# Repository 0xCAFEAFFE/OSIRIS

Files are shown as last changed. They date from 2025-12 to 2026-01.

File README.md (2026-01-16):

## Project OSIRIS

The **O**pen **S**ource **I**onizing **R**adiation **I**ndication **S**ystem can serve as a standalone Geiger counter or dosimeter and as a data logger or true random number generator when connected to a PC. It uses widely available components and is optimized for low power consumption, making it well suited for portable operation.

:construction: The documentation is still under construction. :construction:

### Hardware Overview

The system is powered by a single cell LiPo battery through a soft-latch and MCP1640 boost converter. A high voltage supply provides 400V to the infamous SBM-20 G-M tube for radiation detection, a pulse amplifier shapes the signal for processing by the ATmega328PB microcontroller at the core of the system. A 32kHz clock crystal provides an accurate time base to the MCU. The battery can be charged through the Micro-USB connector and MCP73831 linear charger, the CH340 USB-UART bridge enumerates the device as a virtual serial COM port when connected to a PC, which can be used for updating the firmware, configuration, debugging and logging. A low power, reflective LCD, a foil keypad and an electromechanical beeper form a lean user interface, a 3D-printed snap-fit enclosure keeps everything together in a portable and compact form factor.

The circuit schematics and layout overview is released under *CC BY-NC-SA 4.0* in the `hardware/electronics` folder of this repository.

To deter copycats from profiting off this project without contributing, the manufacturing files are currently not freely available but the bare PCB is available for a symbolic fee in my [Tindie store](https://www.tindie.com/stores/0xcafeaffe/), a partially populated kit is available there as well.

The STL files for the enclosure are released under *CC BY-NC-SA 4.0* and are available in the `hardware/mechanical` folder of this repository and on [Thingiverse](https://www.thingiverse.com/thing:7263135).

### Firmware Overview

The firmware is written in C and implements a interrupt-driven, modular approach using a super-loop. The MCU spends most time in sleep mode to save power but will be woken up by various interrupts, most importantly the G-M radiation events and the 1s tick interrupt provided by the clock XTAL, which triggers the calculation of filtered radiation measurement values. A simple command parser allows the user to control the device through a serial terminal, independently of the UI. To compensate the relatively poor accuracy of the internal RC oscillator, the UART baud rate setting can be calibrated against the external clock XTAL and stored to EEPROM, a modified version of the OptiBoot bootloader loads that calibrated UART setting, which allows for faster firmware upload, which is especially useful during development.

The firmware is released under *GPL v2.0* and available in the `firmware` folder of this repository. It includes a heavily modified version of a [LCD driver library](https://www.lcd-module.de/lcd-tft-beispiel-code-programmierung/application-note/arduino.html), released under *GPL v2.0* as well as a modified version of [OptiBoot](https://github.com/Optiboot/optiboot), released under *GPL v2.0* as well.

### User Interface

Each key has primary functions assigned for short and long key presses:

| Press | Red | Yellow | Green | 
|---|---|---|---|
| Short | Power on / Mute alarm | Toggle clicker  | Cycle view mode |
| Long  | Power off | Toggle key lock | Cycle mode setting |

The following view modes can be cycled through by shortly pressing the green key, in some of which the green key has an alternative function if pressed long:

| View Mode | Green Long Function |  
|---|---|
| Dose Rate | Cycle Filter Setting  |
| Total Dose  | Reset Total Dose |
| Time | Reset System Time |
| Alarm Level | Cycle Alarm Level |
| Voltages | - |

The LCD symbols (no always visible) in the top right corner, from left to right:

 - Keylock enabled
 - Clicker enabled
 - USB connected
 - Battery state
 
The UART calibration routine can be started by holding the yellow key while powering on the device.

### Command Parser

The command parser reads ASCII input from the serial port and expects commands to be terminated with a `LF` character (`'\n', 0x0A`).
Each command consists of a single letter and an optional argument, e.g.: `a` reads out the current alarm level, `a0.5` sets the level to 0.5µSv/h, sending `?` lists all available commands.

The default Windows driver settings for the CH340 cause it to reset the MCU whenever it is connected to the PC or when the COM port is opened. To avoid that, change the following settings:

    Device Manager -> USB-SERIAL CH340 -> Properties -> Port Settings -> Advanced 

```
- [ ] Enabling The Serial Port Enumerator
- [x] Disable Modem Handshake
```

### Build Tools

The application was developed using [Microchip Studio](https://www.microchip.com/en-us/tools-resources/develop/microchip-studio), `v7.0.2594` which ships with the quite old version of `avr-gcc v5.4.0` and `DFP v2.3.518`, the project file for Microchip Studio can be found in the `mcp studio` folder.

If you prefer to build manually and/or with a more recent compiler version, then I suggest downloading this [release by ZakKemble](https://github.com/ZakKemble/avr-gcc-build/releases/tag/v15.1.0-1), which uses the same versions of `avr-gcc v15.1.0`, `binutils v2.44` and `avr-libc v2.2.1` as the latest toolchain [release by Microchip](https://www.microchip.com/en-us/tools-resources/develop/microchip-studio/gcc-compilers), but also includes matching version of `make` and `avrdude` for Windows. The Makefile was only tested on Windows but *should* work for Linux as well. Yes, I'm a Windows person, shame on me, I know, I know..

The bootloader was compiled using `avr-gcc v15.1.0` as well, resulting in a 510 byte binary which *barely* fits the boot section size of 512 bytes. The binary was smaller with the older `avr-gcc v5.4.0`, future compiler versions *might* produce a binary too large to fit.

Fuse settings: Low =0xE2, High =0xD6, Extended =0xFF.

While flashing the bootloader via ISP, USB must be connected to provide power to the system.

In case the default UART setting is way off, the bootloader might not receive the firmware correctly. I'd therefore recommend, when flashing the bootloader via ISP for the first time, to once flash the application via ISP as well, to already have the UART calibration routine in place. Once the application runs, it will auto-calibrate the UART and from there on the bootloader should work as well.

### Warnings :warning:

 - The linear charger is set to a current of 300mA, the connected battery therefore needs to have a capacity of at least 300mAh for a safe charging rate of 1C. 
 - Don't let the battery charge unattended.
 - Don't touch the high voltage path of the PCB while power is on
 - The capacitors stay charged for some for a while after turning off the device.

### Limits

I would expect the device to work up to ~1mSv/h but I don't have a test source strong enough to verify that.

The so called TRNG is only a very primitive draft and the quality of the random numbers was not verified at all.

### Disclaimer 

This device should not be considered a scientific instrument or safety equipment but an experimental development kit for the qualified, radiation-curious professional.

### Contact

Questions and feedback are appreciated!

105112757+0xCAFEAFFE@users.noreply.github.com

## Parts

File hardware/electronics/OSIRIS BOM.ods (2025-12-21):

Reference Designators | Quantity | Technology | Description | Package | Value
C11, C16, C17, C18, C20, C23, C24, C25, C26, C27, C29, C7 | 12 | SMD | Capacitor | 0603 | 100n
J1, J2 | 2 | THT | Tube Holder | FUSE-HOLDER-6.3MM | SBM20
R24 | 1 | SMD | Resistor | 0603 | n.p.
IC7 | 1 | SMD | Microcontroller | TQFP-32 | ATMEGA328PB-AI
C10 | 1 | SMD | Capacitor | 0603 | 2.2n
R33 | 1 | SMD | Resistor | 0603 | 47R
J4 | 1 | THT | Pin Header | 1X05 | ISP
IC1 | 1 | SMD | General purpose CMOS timer IC | SO-8 | ICM7555
T5 | 1 | SMD | N-Channel Mosfet | SOT23-3 | IRLML2502
L1 | 1 | THT | Vertical Ferrite Inductor | L-07HCP | 10m
T3, T4, T6 | 3 | SMD | P-Channel Mosfet | SOT23-3 | IRLML6401
R7 | 1 | SMD | Resistor | 0805 | 1M
R19 | 1 | SMD | Resistor | 0603 | 4.7k
L2 | 1 | SMD | Power Inductor | L-242418FPS | 4.7u
R6 | 1 | SMD | Resistor | 1206 | 1.5M
R20 | 1 | SMD | Resistor | 0603 | 3.3k
C1 | 1 | SMD | Capacitor | 0603 | 1nF
F1, F2 | 2 | SMD | PTC Fuse | 0805 | FSMD035-0805-R
R10, R12, R27 | 3 | SMD | Resistor | 0603 | 10k
D2, D3, D4 | 3 | THT | High Speed Rectifier Diode | D-RADIAL | UF4005
R8, R9 | 2 | SMD | Resistor | 0603 | 220k
IC2 | 1 | SMD | Quad 2-input NOR CMOS IC | SO-14 | 4001D
R21, R22, R26, R28, R29, R30, R31 | 7 | SMD | Resistor | 0603 | 100k
IC5 | 1 | SMD | USB-UART-Bridge IC | SO-16 | CH340C
IC6 | 1 | SMD | Li-Battery Linear Charger IC | SOT23-3-5 | MCP73831
T1 | 1 | SMD | Power Mosfet | DPAK4 | IRFR310
IC3 | 1 | THT | Electromechanical Beeper | BUZZER | BUZZER
R11, R17, R2 | 3 | SMD | Resistor | 0603 | 470k
C21, C22 | 2 | SMD | Capacitor | 0603 | 10pF
C5 | 1 | SMD | Capacitor | 0603 | 4.7n
T2 | 1 | SMD | Bipolar Transistor | SOT23-3 | BC848
C28 | 1 | SMD | Capacitor | 0603 | 220n
D5, D6 | 2 | THT | 200V Zener Diode | D-RADIAL | ZY200
R13, R15, R25, R32 | 4 | SMD | Resistor | 0603 | 1M
BAT1 | 1 | THT | Single Cell Lithium Polymer Battery | JST-2-PTH | 3.7V 3Ah LiPo
J3 | 1 | THT | Micro USB 2.0 Connector | MOLEX_548190519 | MINI-USB
C13, C9 | 2 | SMD | Capacitor | 0603 | 100p
IC8 | 1 | THT | 2x16 Character Low Power LCD | EA-DOGM | EA-DOGM162
R14, R16, R23, R3 | 4 | SMD | Resistor | 0603 | 100R
Y1 | 1 | THT | 32kHz Clock Crystal | TC38 | 32.768kHz
D12 | 1 | SMD | Zener Diode | SOT23-3 | 5.6V
C12, C15, C19 | 3 | SMD | Capacitor | 0805 | 4.7u
IC4 | 1 | SMD | Boost Converter IC | SOT23-3-6 | MCP1640
R1, R18 | 2 | SMD | Resistor | 0603 | 150k
J5 | 1 | THT | Pin Header | 1X04/90 | FOIL KEYPAD
R4, R5 | 2 | SMD | Resistor | 1206 | 1.8M
C2, C3, C4 | 3 | THT | High Voltage Foil Capacitor | MKP2-63022N | 22n
D1, D10, D13, D14, D7, D8, D9 | 7 | SMD | Schottky Diode | SOD-123 | BAT42
C14, C8 | 2 | SMD | Capacitor | 0805 | 22u
C6 | 1 | SMD | Capacitor | 0603 | 47n

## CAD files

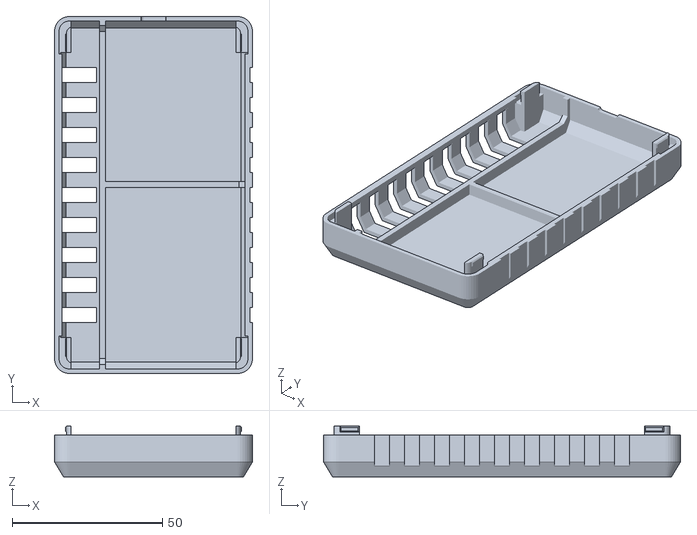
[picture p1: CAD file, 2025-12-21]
hardware/mechanical/Shell_Bottom_v3.stl
66.0 x 119.0 x 16.9

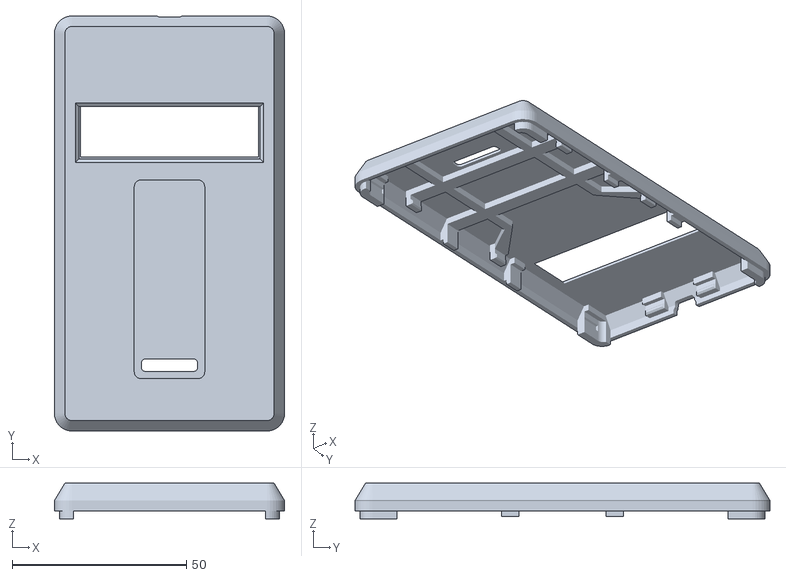
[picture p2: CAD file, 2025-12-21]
hardware/mechanical/Shell_Top_v3.stl
66.0 x 119.0 x 10.2

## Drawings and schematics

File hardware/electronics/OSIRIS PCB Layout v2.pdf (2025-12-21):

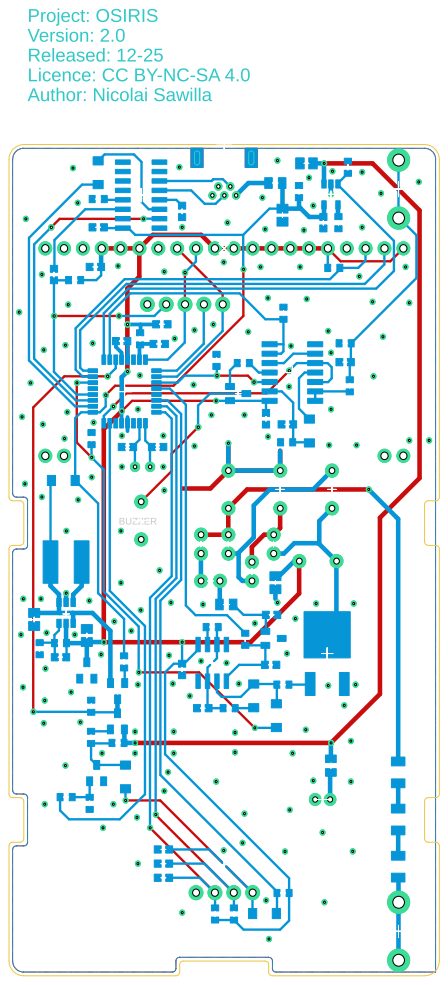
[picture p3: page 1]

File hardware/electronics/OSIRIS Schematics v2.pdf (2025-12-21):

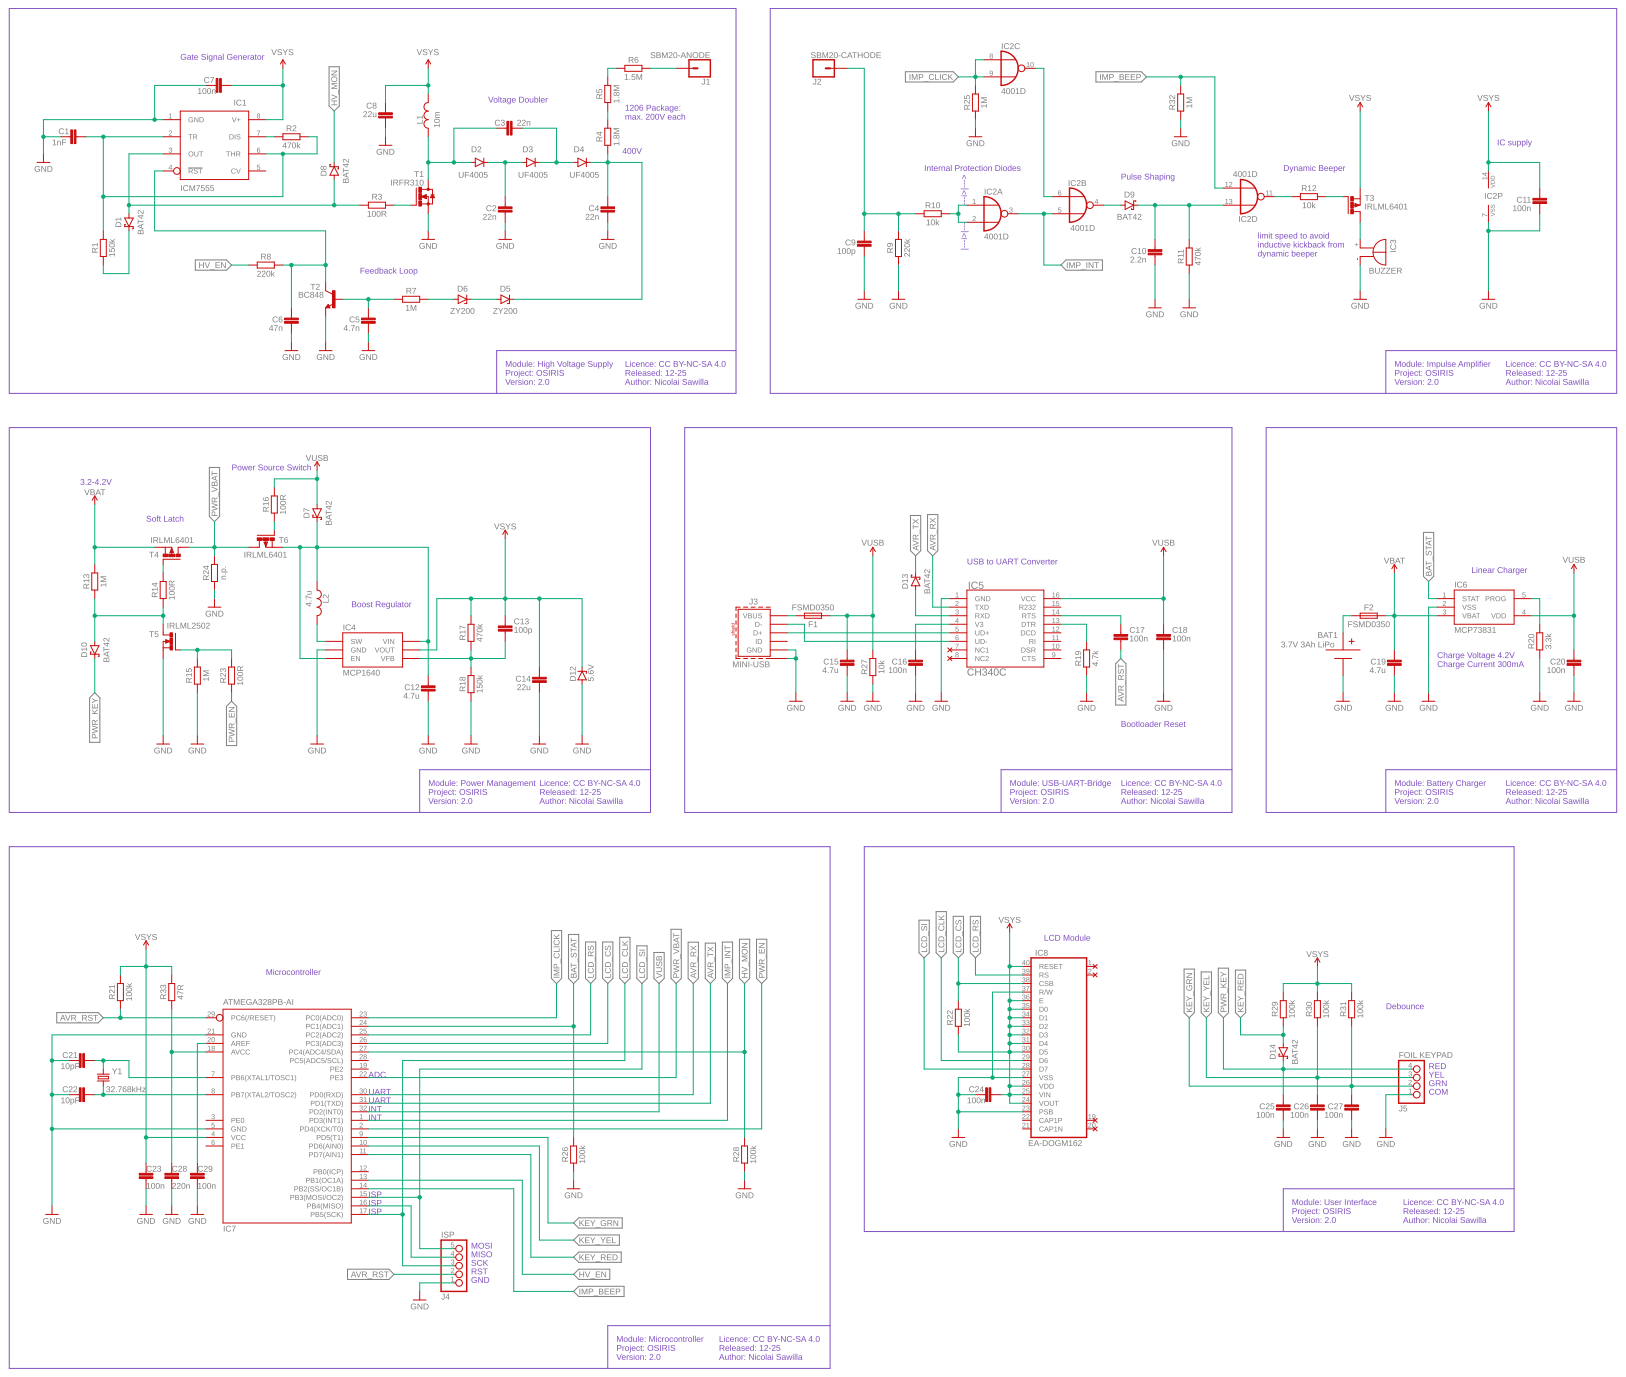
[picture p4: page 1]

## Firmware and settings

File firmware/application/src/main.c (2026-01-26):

/*
===============================================================================
 Project	: O.S.I.R.I.S.
 Author		: Nicolai Sawilla (0xCAFEAFFE)
 Licence	: GNU GPL v2
 Version	: v2.0 (PCB Rev 2.0)
 Content	: Main application source
===============================================================================
*/

#include "adc.h"
#include "cmd.h"
#include "gpio.h"
#include "keys.h"
#include "lcd.h"
#include "pwr.h"
#include "rad.h"
#include "rtc.h"
#include "sys.h"
#include "uart.h"
#include "ui.h"

// revision defines
#define HW_REV	"2.0"
#define FW_REV	"2.21"

// internal function prototypes
static bool InitSystem(void);

// application boot vector
int main(void)
{
	// initialize all subsystems
	bool ok = InitSystem();
	SYS_Assert(ok);

	// ================ main loop ================
	// this block will execute after wake-up from any enabled interrupt:
	// sec tick (TIMER2_OVF), UART (USART0_UDRE, USART0_RX), rad event (INT1/PCINT1), keys (PCINT2/TIMER2_COMPA), USB dis/connect (INT0)
	while (true)
	{
		// handle UART only if enabled
		if (UART_GetEnabled())
		{
			// try to read string from UART & parse command
			char str[UART_RX_BUF_SIZE] = {0};
			if (UART_RxString(str))
			{
				CMD_Parse(str);
			}
			else // let random numbers be independent of UART
			{
				// seed PRNG sequencer with value of free running T1
				// T2 overflow is not synchronized to T1, detector interrupts are truly random
				// note: I/O clock to T1 is halted during sleep, this RNG might not be great..
				srand((unsigned int)TCNT1);
			}
		}

		// flag is set by T2 ISR every second
		if (RTC_CheckSecTick())
		{
			// reset watchdog (2s timeout)
			wdt_reset();

			// monitor HV & tube, process radiation data, logging
			RAD_EngineTick();
		
			// handle UI
			UI_CheckAlarm();
			UI_UpdateBattery();
			UI_RenderLcd();
		}
		
		// check if key was pressed
		byte key = KEYS_GetEvents();
		if (key)
		{
			UI_HandleKeys(key);
			UI_RenderLcd();
		}

		// check if USB was connected or disconnected
		if (PWR_CheckUsbEvent())
		{
			LCD_Clear();
			UI_RenderLcd();
		}

		// wait until UART is idle before entering sleep mode
		while (UART_TxBusy());
		
		// go to sleep to save power until interrupt wakes us up again
		PWR_SleepMode();
		
	} // end main loop

	return 0; // the cake is a lie
}

// initialize all hardware & firmware modules
static bool InitSystem(void)
{
	// reset watchdog ASAP after boot
	MCUSR = 0;				// clear reset flags (incl. WDRF)
	wdt_reset();
	wdt_enable(WDTO_8S);	// 8s timeout should be sufficient for init
	
	// init GPIO pins & start-up beep
	GPIO_Init();
	GPIO_SetPin(PIN_BEEP_EN, true);
	_delay_ms(100); // this also ensures that key caps are charged
	GPIO_SetPin(PIN_BEEP_EN, false);

	// init USB dis/connect detection
	PWR_Init();
	
	// global interrupt enable - needed for UART
	sei();
	
	// init UART soon after boot so it can be used for debugging
	bool cal_ok = UART_Init();
	UART_Printf("OSIRIS HW v%s FW v%s\n", HW_REV, FW_REV);
	UART_Printf("Init..\n");
	
	// also calibrate UART if yellow key held during boot
	cal_ok &= GPIO_GetPin(PIN_KEY_YEL); 

	// LCD init
 	LCD_Init();
 	LCD_Printf(1, "OSIRIS");
 	LCD_Printf(2, "HW v%s FW v%s", HW_REV, FW_REV);
	
	// init Timer2, needed for systick and RTC
	if (!RTC_InitRtc())
	{
		LCD_Clear();
		LCD_Printf(1, "RTC FAULT !!");
		UART_Printf("RTC FAULT !!");
		return false;
	}

	// run UART calibration if invalid or requested
	if (!cal_ok)
	{
		LCD_Clear();
		LCD_Printf(1, "UART cal..");
		
		bool ok = UART_Calibrate(true);
		
		LCD_Printf(2, ok?"OK!":"ERROR!");
		_delay_ms(1000); // keep message visible for a while
	}
	
	// initialize ADC
	if (!ADC_Init())
	{
		LCD_Clear();
		LCD_Printf(1, "ADC FAULT !!");
		UART_Printf("ADC FAULT !!");
		return false;
	}

	// enable & check radiation detection circuit
	if (!RAD_Init())
	{
		LCD_Clear();
		LCD_Printf(1, "HV FAULT !!");
		return false;
	}

	// init user interface detection
	KEYS_Init();
	UI_Init();
	
	// start T1 for RNG, prescaler 1
	SET(TCCR1B, CS10);
	
	UART_Printf("Ready!\n");
	UART_Printf("Enter '?' for help.\n");

	// enable watchdog - reset every second in main loop
	wdt_reset();
	wdt_enable(WDTO_2S);

	return true;
}

// -------------------------------------- EOF --------------------------------------

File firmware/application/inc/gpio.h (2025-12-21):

/*
===============================================================================
 Project	: O.S.I.R.I.S.
 Author		: Nicolai Sawilla (0xCAFEAFFE)
 Licence	: GNU GPL v2
 Version	: v2.0 (PCB Rev 2.0)
 Content	: Public interface for GPIO functions
===============================================================================
*/

#ifndef GPIO_H_
#define GPIO_H_

#include "sys.h"

// GPIO pin property struct
typedef struct
{
	// 7 bits total
	byte port	: 2;	// register block	(B/C/D/E)
	byte n		: 3;	// pin number		(0..7)
	bool dir	: 1;	// direction		(0=in/1=out)
	bool init	: 1;	// default state	(0=lo/1=hi)
} GPIO_PinStruct_t;

// GPIO port enum
typedef enum
{
	PB = 0u,
	PC = 1u,
	PD = 2u,
	PE = 3u
} GPIO_Port_t;

// pin names
typedef enum
{
	PIN_RAD_IMP		= 0u,
	PIN_VREG_EN		= 1u,
	PIN_RFU1		= 2u, // reserved for future use
	PIN_RFU2		= 3u,
	PIN_KEY_GRN		= 4u,
	PIN_KEY_YEL		= 5u,
	PIN_KEY_RED		= 6u,
	PIN_RFU3		= 7u,
	PIN_HV_EN		= 8u,
	PIN_BEEP_EN		= 9u,
	PIN_SPI_MOSI	= 10u,
	PIN_SPI_MISO	= 11u,
	PIN_SPI_SCK		= 12u,
	PIN_RFU4		= 13u,
	PIN_CLICK_EN	= 14u,
	PIN_BAT_STAT	= 15u,
	PIN_LCD_RS		= 16u,
	PIN_LCD_CS		= 17u,
	PIN_HV_GATE		= 18u,
	PIN_RFU5		= 19u,
	PIN_UART_RX		= 20u,
	PIN_UART_TX		= 21u,
	PIN_VUSB		= 22u,
	PIN_NUM			= 23u // needs to be the last one
} GPIO_Pin_t;

// pin name mapping
static const __flash GPIO_PinStruct_t gpio[PIN_NUM] =
{
	// port, pin, dir, init
	{PD,3u,IN,LO},	// PD3 - IMP_INT
	{PD,4u,OUT,HI}, // PD4 - PWR_EN
	{PE,0u,IN,HI},	// PE0 - [unused]
	{PE,1u,IN,HI},	// PE1 - [unused]
	{PD,5u,IN,LO},	// PD5 - KEY_GRN
	{PD,6u,IN,LO},	// PD6 - KEY_YEL
	{PD,7u,IN,LO},	// PD7 - KEY_RED
	{PB,0u,IN,HI},	// PB0 - [unused]
	{PB,1u,OUT,LO}, // PB1 - HV_EN
	{PB,2u,OUT,LO}, // PB2 - IMP_BEEP_EN
	{PB,3u,OUT,HI}, // PB3 - LCD_SI
	{PB,4u,IN,LO},	// PB4 - MISO
	{PB,5u,OUT,HI}, // PB5 - LCD_CLK
	{PE,2u,IN,HI},	// PE2 - [unused]
	{PC,0u,OUT,LO}, // PC0 - IMP_CLICK_EN
	{PC,1u,IN,LO},  // PC1 - BAT_STAT
	{PC,2u,OUT,HI}, // PC2 - LCD_RS
	{PC,3u,OUT,HI}, // PC3 - LCD_CS
	{PC,4u,IN,LO},	// PC4 - HV_MON
	{PC,5u,IN,HI},	// PC5 - [unused]
	{PD,0u,IN,LO},	// PD0 - RX
	{PD,1u,OUT,HI}, // PD1 - TX
	{PD,2u,IN,LO},	// PD2 - VUSB
};

// public function declarations
void GPIO_Init(void);
void GPIO_ConfigPin(byte gpiopin, bool state);
void GPIO_SetPin(byte gpiopin, bool state);
bool GPIO_GetPin(byte gpiopin);
void GPIO_PullupPin(byte gpiopin, bool enable);
void GPIO_TogglePin(byte gpiopin);

#endif /* GPIO_H_ */

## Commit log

2026-01-05 Increase dose rate filter time constants
2026-01-06 Move files
    [OSIRIS BOM.ods, Shell_Bottom_v3.stl, Shell_Top_v3.stl]
2026-01-06 Shorten help strings, saves a few bytes
    [cmd.c]
2026-01-09 Remove reset of UBRR in EEP on FE
    [uart.c]
2026-01-12 Add persistence of total accumulated dose between resets
    [cmd.c, pwr.c, rad.c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]
2026-01-16 Add shutdown message, Add reset of systime
    [pwr.c, ui.c]
